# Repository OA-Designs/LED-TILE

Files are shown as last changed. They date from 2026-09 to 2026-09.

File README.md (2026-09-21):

# Modular LED Lighting Tiles

Modular decorative LED tiles in multiple shapes (hex, square, triangle...) sharing one PCB design. Tiles connect edge-to-edge to share power and sync lighting effects across a network. This project is a work in progress and incomplete.

## Overview

Each tile is an independent, battery-powered LED node built around an ESP32-C3, with USB-C charging and a shared power/data bus that lets tiles connect edge to edge. Tiles can pull power from and push power to their neighbors, so a single plugged-in tile can charge several unpowered neighbors at once. The same PCB design drops into enclosures of different shapes (hexagon, square, triangle, pentagon, circular), so the electronics are built once and reused across every form factor.

**Key design points:**
- **Priority power management:** a hardware power mux automatically prefers wired USB power over battery, with no firmware involvement, so LEDs always run off wired power when it's available and switch to battery seamlessly when it's not.
- **LiFePO4 battery charging:** a dedicated charger IC handles battery charging independently of the tile's own power draw, so charging doesn't compete with LED brightness for current budget.
- **Tile-to-tile mesh network:** tiles discover their neighbors automatically over a UART mesh, elect a master per connected group ("island"), and stream synchronized lighting effects across the whole group enabling smooth cross-tile animations like spirals and waves that flow across tile boundaries.
- **Multi-island coordination:** each island's master connects over WiFi to a central coordinator, so multiple physically separate groups of tiles can be synced together.
- **Shape-agnostic PCB:** the same board and firmware work across every enclosure shape; only the physical tile body changes.

## Status

Schematic and PCB layout are complete (4-layer board, DRC clean). Not yet fabricated or bench-tested — feedback and review are very welcome before I send this off for manufacturing.

## Repo Structure
- **Electronics:**          KiCad project files for the shared PCB (schematic, layout, plots)
- **Enclosures:**           Mechanical designs for each tile shape (hexagon, square, triangle, etc.)
- **Docs:**                 Design notes, shared dimensions reference, process history

## View the PCB

The full schematic and PCB layout can be explored interactively (pan, zoom, toggle layers, click any trace to see its net) via KiCanvas:
PLACEHOLDERS
- [Schematic](https://kicanvas.org/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)
- [PCB Layout](https://kicanvas.org/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)

## Design Process

This design went through several rounds of community feedback before reaching its current state — including a full rework of the power/charging circuit, switching to an external-antenna module for layout flexibility, and a move from 2 to 4 layers to resolve routing density. If you're curious about the reasoning behind specific decisions, feel free to open an issue or start a discussion.

## License

Licensed under [GNU GPL v3.0](LICENSE). Modifications and derivatives must remain open source under the same license.

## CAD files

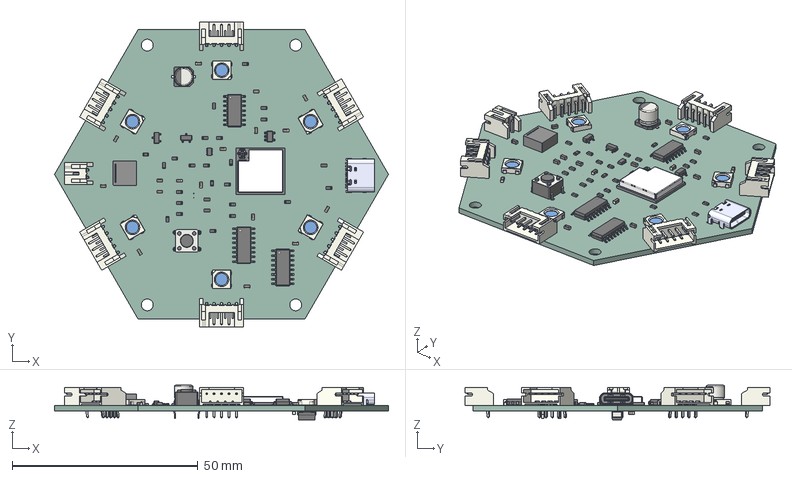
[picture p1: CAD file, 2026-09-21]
electronics/lighting-tile-pcb/Lighting Tile Circuit V3.step
90.0 x 82.1 x 9.30 mm
C_0603_1608Metric x 18
R_0603_1608Metric x 26
LED_WS2812B_PLCC4_50x50mm_P32mm x 6
JST_S2B_PH_K
SW_PUSH_6mm
JST_S5B_PH_K x 6
XAL6030-102MEB
SOT-23-5
SOT-23 x 2
CP_Elec_5x54
TYPE-C-31-M-12
SOIC-14_3.9x8.7mm_P1.27mm
C0402_20210301.STEP^C0402_20210301.STEP_Submodel-C0402_part_ DesignRootModel_PCB_ESP32-C3-MINI-1U_V2(2)_PCB_ESP32-C3-MINI-1U_V2
R0201_20210301.STEP^R0201_20210301.STEP_Submodel-R0201_part_ DesignRootModel_PCB_ESP32-C3-MINI-1U_V2(2)_PCB_ESP32-C3-MINI-1U_V2 x 3
L0201_20210301.STEP^L0201_20210301.STEP_Submodel-L0201_part_ DesignRootModel_PCB_ESP32-C3-MINI-1U_V2(2)_PCB_ESP32-C3-MINI-1U_V2 x 2
C0201_20210301.STEP^C0201_20210301.STEP_Submodel-C0201_part_ DesignRootModel_PCB_ESP32-C3-MINI-1U_V2(2)_PCB_ESP32-C3-MINI-1U_V2 x 11
ESP32-C3_20210301.STEP^ESP32-C3_20210301.STEP_Submodel-QFN32_0P5_5_ part_DesignRootModel_PCB_ESP32-C3-MINI-1U_V2(2)_PCB_ESP32-C3-MINI-1U_V2
DFN1006.STEP^DFN1006.STEP_Submodel-SOD882_part_DesignRootModel_PCB_ ESP32-C3-MINI-1U_V2(2)_PCB_ESP32-C3-MINI-1U_V2
XTAL3225_20210301.STEP^XTAL3225_20210301.STEP_Submodel-XTAL3225_part_ DesignRootModel_PCB_ESP32-C3-MINI-1U_V2(2)_PCB_ESP32-C3-MINI-1U_V2
ipx3.STEP^ipx3.STEP_Submodel-IPEX_4P_part_DesignRootModel_PCB_ ESP32-C3-MINI-1U_V2(2)_PCB_ESP32-C3-MINI-1U_V2
uid__4^DesignRootModel_PCB_ESP32-C3-MINI-1U_V2(2)_PCB_ESP32-C3-MINI-1U_ V2
uid__4-15^DesignRootModel_PCB_ESP32-C3-MINI-1U_V2(2)_PCB_ ESP32-C3-MINI-1U_V2
uid__4-16^DesignRootModel_PCB_ESP32-C3-MINI-1U_V2(2)_PCB_ ESP32-C3-MINI-1U_V2
uid__4-17^DesignRootModel_PCB_ESP32-C3-MINI-1U_V2(2)_PCB_ ESP32-C3-MINI-1U_V2
uid__4-18^DesignRootModel_PCB_ESP32-C3-MINI-1U_V2(2)_PCB_ ESP32-C3-MINI-1U_V2
uid__4-19^DesignRootModel_PCB_ESP32-C3-MINI-1U_V2(2)_PCB_ ESP32-C3-MINI-1U_V2
uid__4-20^DesignRootModel_PCB_ESP32-C3-MINI-1U_V2(2)_PCB_ ESP32-C3-MINI-1U_V2
uid__4-21^DesignRootModel_PCB_ESP32-C3-MINI-1U_V2(2)_PCB_ ESP32-C3-MINI-1U_V2
uid__4-22^DesignRootModel_PCB_ESP32-C3-MINI-1U_V2(2)_PCB_ ESP32-C3-MINI-1U_V2
uid__4-23^DesignRootModel_PCB_ESP32-C3-MINI-1U_V2(2)_PCB_ ESP32-C3-MINI-1U_V2
uid__4-24^DesignRootModel_PCB_ESP32-C3-MINI-1U_V2(2)_PCB_ ESP32-C3-MINI-1U_V2
uid__4-25^DesignRootModel_PCB_ESP32-C3-MINI-1U_V2(2)_PCB_ ESP32-C3-MINI-1U_V2
uid__4-26^DesignRootModel_PCB_ESP32-C3-MINI-1U_V2(2)_PCB_ ESP32-C3-MINI-1U_V2
uid__4-37^DesignRootModel_PCB_ESP32-C3-MINI-1U_V2(2)_PCB_ ESP32-C3-MINI-1U_V2
uid__4-38^DesignRootModel_PCB_ESP32-C3-MINI-1U_V2(2)_PCB_ ESP32-C3-MINI-1U_V2
uid__4-48^DesignRootModel_PCB_ESP32-C3-MINI-1U_V2(2)_PCB_ ESP32-C3-MINI-1U_V2
uid__4-49^DesignRootModel_PCB_ESP32-C3-MINI-1U_V2(2)_PCB_ ESP32-C3-MINI-1U_V2
uid__4-58^DesignRootModel_PCB_ESP32-C3-MINI-1U_V2(2)_PCB_ ESP32-C3-MINI-1U_V2
uid__4-59^DesignRootModel_PCB_ESP32-C3-MINI-1U_V2(2)_PCB_ ESP32-C3-MINI-1U_V2
uid__4-65^DesignRootModel_PCB_ESP32-C3-MINI-1U_V2(2)_PCB_ ESP32-C3-MINI-1U_V2
uid__4-66^DesignRootModel_PCB_ESP32-C3-MINI-1U_V2(2)_PCB_ ESP32-C3-MINI-1U_V2
uid__4-67^DesignRootModel_PCB_ESP32-C3-MINI-1U_V2(2)_PCB_ ESP32-C3-MINI-1U_V2
uid__4-69^DesignRootModel_PCB_ESP32-C3-MINI-1U_V2(2)_PCB_ ESP32-C3-MINI-1U_V2
uid__4-70^DesignRootModel_PCB_ESP32-C3-MINI-1U_V2(2)_PCB_ ESP32-C3-MINI-1U_V2
uid__4-76^DesignRootModel_PCB_ESP32-C3-MINI-1U_V2(2)_PCB_ ESP32-C3-MINI-1U_V2
uid__4-77^DesignRootModel_PCB_ESP32-C3-MINI-1U_V2(2)_PCB_ ESP32-C3-MINI-1U_V2
uid__4-84^DesignRootModel_PCB_ESP32-C3-MINI-1U_V2(2)_PCB_ ESP32-C3-MINI-1U_V2
uid__4-85^DesignRootModel_PCB_ESP32-C3-MINI-1U_V2(2)_PCB_ ESP32-C3-MINI-1U_V2
uid__4-87^DesignRootModel_PCB_ESP32-C3-MINI-1U_V2(2)_PCB_ ESP32-C3-MINI-1U_V2
uid__4-88^DesignRootModel_PCB_ESP32-C3-MINI-1U_V2(2)_PCB_ ESP32-C3-MINI-1U_V2
uid__4-89^DesignRootModel_PCB_ESP32-C3-MINI-1U_V2(2)_PCB_ ESP32-C3-MINI-1U_V2
uid__4-91^DesignRootModel_PCB_ESP32-C3-MINI-1U_V2(2)_PCB_ ESP32-C3-MINI-1U_V2
uid__4-92^DesignRootModel_PCB_ESP32-C3-MINI-1U_V2(2)_PCB_ ESP32-C3-MINI-1U_V2
uid__4-100^DesignRootModel_PCB_ESP32-C3-MINI-1U_V2(2)_PCB_ ESP32-C3-MINI-1U_V2
uid__4-101^DesignRootModel_PCB_ESP32-C3-MINI-1U_V2(2)_PCB_ ESP32-C3-MINI-1U_V2
uid__4-110^DesignRootModel_PCB_ESP32-C3-MINI-1U_V2(2)_PCB_ ESP32-C3-MINI-1U_V2
uid__4-111^DesignRootModel_PCB_ESP32-C3-MINI-1U_V2(2)_PCB_ ESP32-C3-MINI-1U_V2
uid__4-112^DesignRootModel_PCB_ESP32-C3-MINI-1U_V2(2)_PCB_ ESP32-C3-MINI-1U_V2
uid__4-113^DesignRootModel_PCB_ESP32-C3-MINI-1U_V2(2)_PCB_ ESP32-C3-MINI-1U_V2
uid__4-117^DesignRootModel_PCB_ESP32-C3-MINI-1U_V2(2)_PCB_ ESP32-C3-MINI-1U_V2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

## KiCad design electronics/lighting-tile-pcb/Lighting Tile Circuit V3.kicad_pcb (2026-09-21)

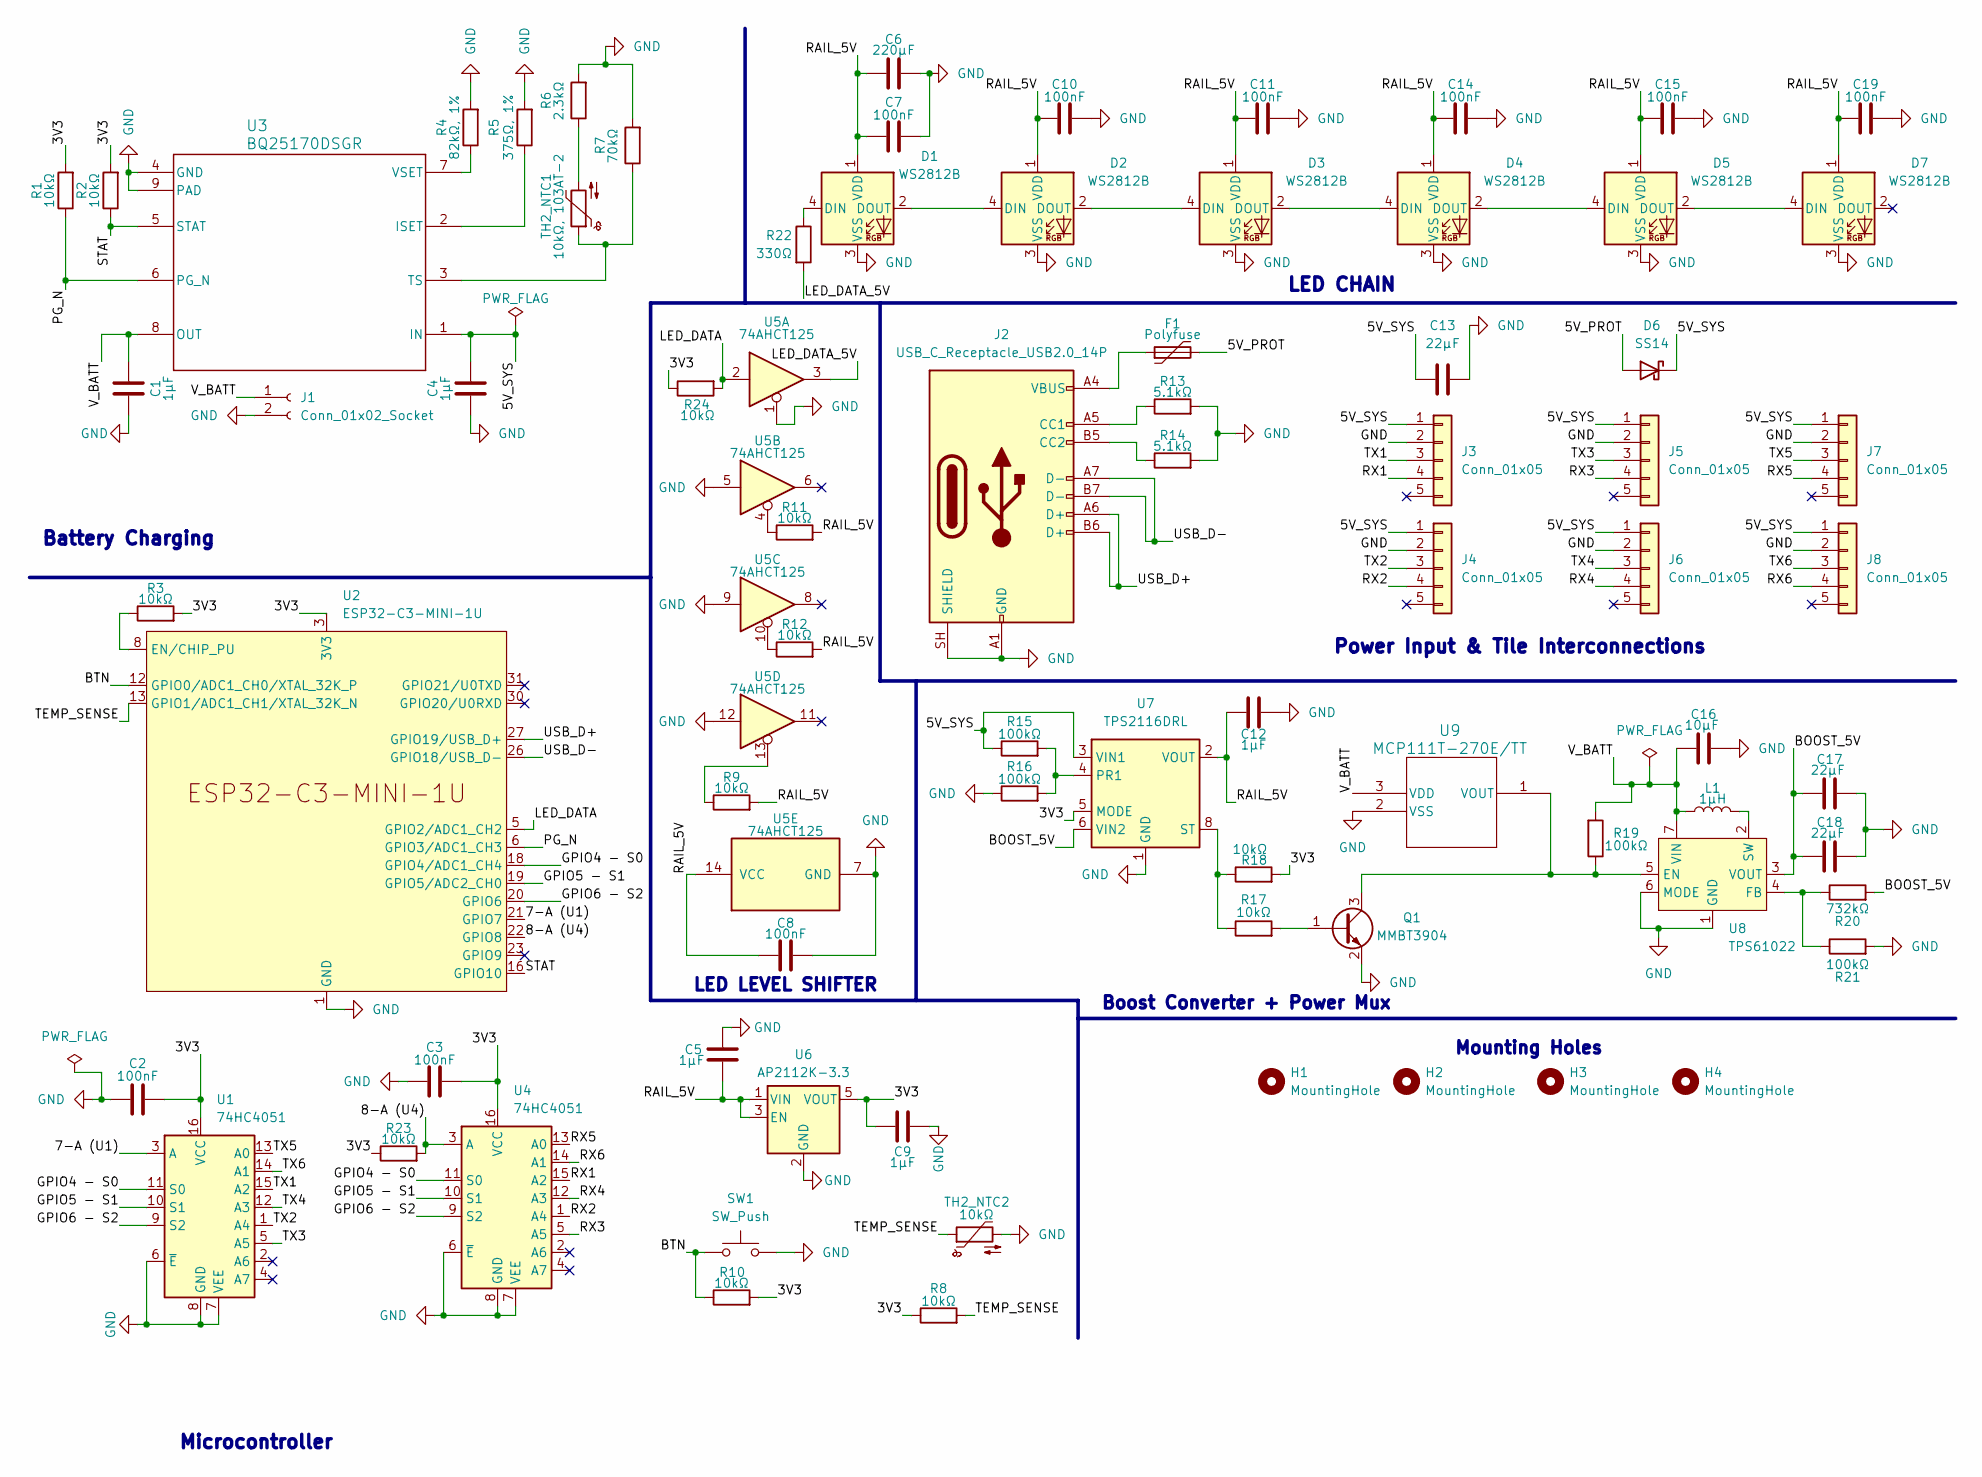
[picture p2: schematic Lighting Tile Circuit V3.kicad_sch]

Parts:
C1, C4, C5, C9: 1µF; C_0603_1608Metric_Pad1.08x0.95mm_HandSolder
C2, C3, C7, C8, C10, C11, C14, C15, C19: 100nF; C_0603_1608Metric_Pad1.08x0.95mm_HandSolder
C6: 220µF; CP_Elec_5x5.4
C12: 1μF; C_0603_1608Metric_Pad1.08x0.95mm_HandSolder
C13: 22µF; C_0603_1608Metric_Pad1.08x0.95mm_HandSolder
C16: 10μF; C_0603_1608Metric_Pad1.08x0.95mm_HandSolder
C17, C18: 22μF; C_0603_1608Metric_Pad1.08x0.95mm_HandSolder
D1, D2, D3, D4, D5, D7: WS2812B; LED_WS2812B_PLCC4_5.0x5.0mm_P3.2mm
D6: SS14; D_SMA
F1: Polyfuse; Fuse_1210_3225Metric_Pad1.42x2.65mm_HandSolder
H1, H2, H3, H4: MountingHole; MountingHole_3.2mm_M3
J1: Conn_01x02_Socket; JST_PH_S2B-PH-K_1x02_P2.00mm_Horizontal
J2: USB_C_Receptacle_USB2.0_14P; USB_C_Receptacle_HRO_TYPE-C-31-M-12
J3, J4, J5, J6, J7, J8: Conn_01x05; JST_PH_S5B-PH-K_1x05_P2.00mm_Horizontal
L1: 1μH; IND_XAL6030-102MEC
Q1: MMBT3904; SOT-23_Handsoldering
R1, R2, R3, R8, R9, R10, R11, R12, R17, R18, R23, R24: 10kΩ; R_0603_1608Metric_Pad0.98x0.95mm_HandSolder
R4: 82kΩ, 1%; R_0603_1608Metric_Pad0.98x0.95mm_HandSolder
R5: 375Ω, 1%; R_0603_1608Metric_Pad0.98x0.95mm_HandSolder
R6: 2.3kΩ; R_0603_1608Metric_Pad0.98x0.95mm_HandSolder
R7: 70kΩ; R_0603_1608Metric_Pad0.98x0.95mm_HandSolder
R13, R14: 5.1kΩ; R_0603_1608Metric_Pad0.98x0.95mm_HandSolder
R15, R16, R19, R21: 100kΩ; R_0603_1608Metric_Pad0.98x0.95mm_HandSolder
R20: 732kΩ; R_0603_1608Metric_Pad0.98x0.95mm_HandSolder
R22: 330Ω; R_0603_1608Metric_Pad0.98x0.95mm_HandSolder
SW1: SW_Push; SW_PUSH_6mm
TH2_NTC1: 10kΩ, 103AT-2; R_0603_1608Metric_Pad0.98x0.95mm_HandSolder
TH2_NTC2: 10kΩ; R_0603_1608Metric_Pad0.98x0.95mm_HandSolder
U1, U4: 74HC4051; SOIC-16_3.9x9.9mm_P1.27mm
U2: ESP32-C3-MINI-1U
U3: BQ25170DSGR; DSG0008A
U5: 74AHCT125; SOIC-14_3.9x8.7mm_P1.27mm
U6: AP2112K-3.3; SOT-23-5
U7: TPS2116DRL; SOT-583-8
U8: TPS61022; Texas_RWU0007A_VQFN-7_2x2mm_P0.5mm
U9: MCP111T-270E/TT; SOT-23_Handsoldering

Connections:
/3V3: C2.2, C3.2, C9.1, R1.2, R2.2, R3.2, R8.1, R10.2, R18.2, R23.1, R24.1, U1.16 (VCC), U2.3 (3V3), U4.16 (VCC), U6.5 (VOUT), U7.5 (MODE)
/5V_PROT: D6.2 (A), F1.2
/5V_SYS: C4.2, C13.1, D6.1 (K), J3.1, J4.1, J5.1, J6.1, J7.1, J8.1, R15.1, U3.1 (IN), U7.3 (VIN1)
/7-A (U1): U1.3 (A), U2.21 (GPIO7)
/8-A (U4): R23.2, U2.22 (GPIO8), U4.3 (A)
/BOOST_5V: C17.1, C18.1, R20.2, U7.6 (VIN2), U8.3 (VOUT)
/BTN: R10.1, SW1.1, U2.12 (GPIO0/ADC1_CH0/XTAL_32K_P)
/GPIO4 - S0: U1.11 (S0), U2.18 (GPIO4/ADC1_CH4), U4.11 (S0)
/GPIO5 - S1: U1.10 (S1), U2.19 (GPIO5/ADC2_CH0), U4.10 (S1)
/GPIO6 - S2: U1.9 (S2), U2.20 (GPIO6), U4.9 (S2)
/LED_DATA: R24.2, U2.5 (GPIO2/ADC1_CH2), U5.2
/LED_DATA_5V: R22.2, U5.3
/PG_N: R1.1, U2.6 (GPIO3/ADC1_CH3), U3.6 (PG_N)
/RAIL_5V: C5.1, C6.1, C7.1, C8.1, C10.1, C11.1, C12.1, C14.1, C15.1, C19.1, D1.1 (VDD), D2.1 (VDD), D3.1 (VDD), D4.1 (VDD), D5.1 (VDD), D7.1 (VDD), R9.2, R11.2, R12.2, U5.14 (VCC), U6.1 (VIN), U6.3 (EN), U7.2 (VOUT), U7.7 (VOUT)
/RX1: J3.4, U4.15 (A2)
/RX2: J4.4, U4.1 (A4)
/RX3: J5.4, U4.5 (A5)
/RX4: J6.4, U4.12 (A3)
/RX5: J7.4, U4.13 (A0)
/RX6: J8.4, U4.14 (A1)
/STAT: R2.1, U2.16 (GPIO10), U3.5 (STAT)
/TEMP_SENSE: R8.2, TH2_NTC2.1, U2.13 (GPIO1/ADC1_CH1/XTAL_32K_N)
/TX1: J3.3, U1.15 (A2)
/TX2: J4.3, U1.1 (A4)
/TX3: J5.3, U1.5 (A5)
/TX4: J6.3, U1.12 (A3)
/TX5: J7.3, U1.13 (A0)
/TX6: J8.3, U1.14 (A1)
/USB_D+: J2.A6 (D+), J2.B6 (D+), U2.27 (GPIO19/USB_D+)
/USB_D-: J2.A7 (D-), J2.B7 (D-), U2.26 (GPIO18/USB_D-)
/V_BATT: C1.2, C16.1, J1.1, L1.1, R19.2, U3.8 (OUT), U8.7 (VIN), U9.3 (VDD)
GND: C1.1, C2.1, C3.1, C4.1, C5.2, C6.2, C7.2, C8.2, C9.2, C10.2, C11.2, C12.2, C13.2, C14.2, C15.2, C16.2, C17.2, C18.2, C19.2, D1.3 (VSS), D2.3 (VSS), D3.3 (VSS), D4.3 (VSS), D5.3 (VSS), D7.3 (VSS), J1.2, J2.A1 (GND), J2.A12 (GND), J2.B1 (GND), J2.B12 (GND), J2.SH (SHIELD), J3.2, J4.2, J5.2, J6.2, J7.2, J8.2, Q1.2 (E), R4.2, R5.2, R6.2, R7.2, R13.2, R14.2, R16.1, R21.2, SW1.2, TH2_NTC2.2, U1.6 (~E), U1.7 (VEE), U1.8 (GND), U2.1 (GND), U2.2 (GND), U2.11 (GND), U2.14 (GND), U2.36 (GND), U2.37 (GND), U2.38 (GND), U2.39 (GND), U2.40 (GND), U2.41 (GND), U2.42 (GND), U2.43 (GND), U2.44 (GND), U2.45 (GND), U2.46 (GND), U2.47 (GND), U2.48 (GND), U2.49 (GND), U2.50 (GND), U2.51 (GND), U2.52 (GND), U2.53 (GND), U3.4 (GND), U3.9 (PAD), U3.10, U3.11, U4.6 (~E), U4.7 (VEE), U4.8 (GND), U5.1, U5.5, U5.7 (GND), U5.9, U5.12, U6.2 (GND), U7.1 (GND), U8.1 (GND), U8.6 (MODE), U9.2 (VSS)
unnamed: D1.4 (DIN), R22.1
unnamed: D1.2 (DOUT), D2.4 (DIN)
unnamed: D2.2 (DOUT), D3.4 (DIN)
unnamed: D3.2 (DOUT), D4.4 (DIN)
unnamed: D4.2 (DOUT), D5.4 (DIN)
unnamed: D5.2 (DOUT), D7.4 (DIN)
unnamed: F1.1, J2.A4 (VBUS), J2.A9 (VBUS), J2.B4 (VBUS), J2.B9 (VBUS)
unnamed: J2.A5 (CC1), R13.1
unnamed: J2.B5 (CC2), R14.1
unnamed: Q1.1 (B), R17.2
unnamed: Q1.3 (C), R19.1, U8.5 (EN), U9.1 (VOUT)
unnamed: R6.1, TH2_NTC1.2
unnamed: R9.1, U5.13
unnamed: R11.1, U5.4
unnamed: R12.1, U5.10
unnamed: R3.1, U2.8 (EN/CHIP_PU)
unnamed: R5.1, U3.2 (ISET)
unnamed: R7.1, TH2_NTC1.1, U3.3 (TS)
unnamed: R4.1, U3.7 (VSET)
unnamed: R15.2, R16.2, U7.4 (PR1)
unnamed: R17.1, R18.1, U7.8 (ST)
unnamed: R20.1, R21.1, U8.4 (FB)
unnamed: L1.2, U8.2 (SW)

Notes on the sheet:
Power Input & Tile Interconnections
LED CHAIN
LED LEVEL SHIFTER
Battery Charging
Mounting Holes
Microcontroller
Boost Converter + Power Mux

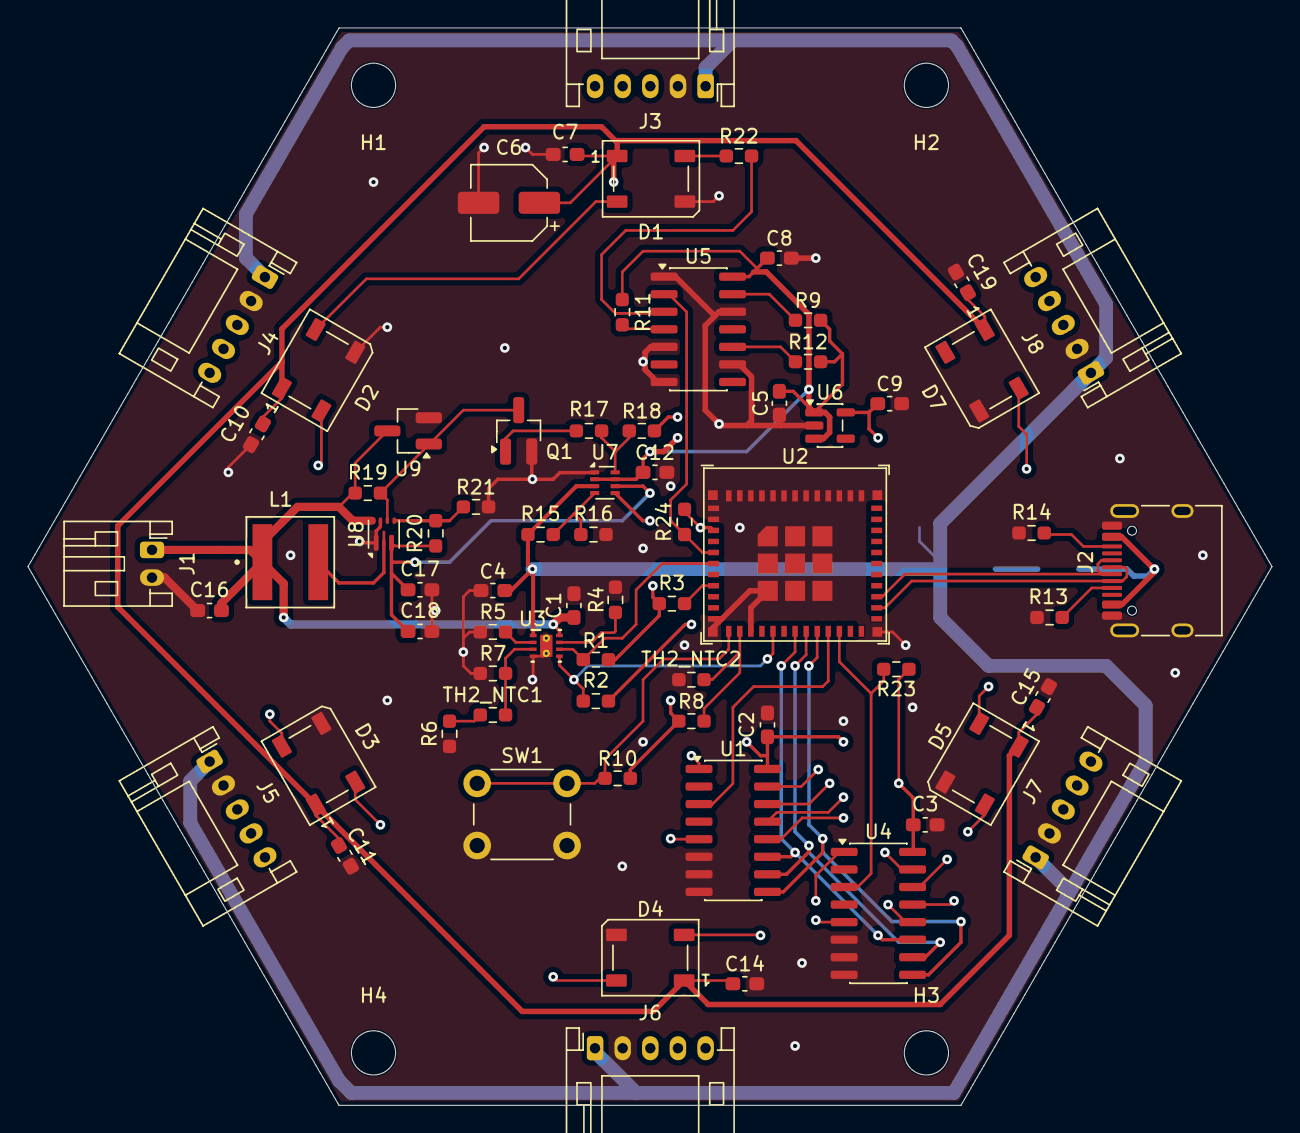
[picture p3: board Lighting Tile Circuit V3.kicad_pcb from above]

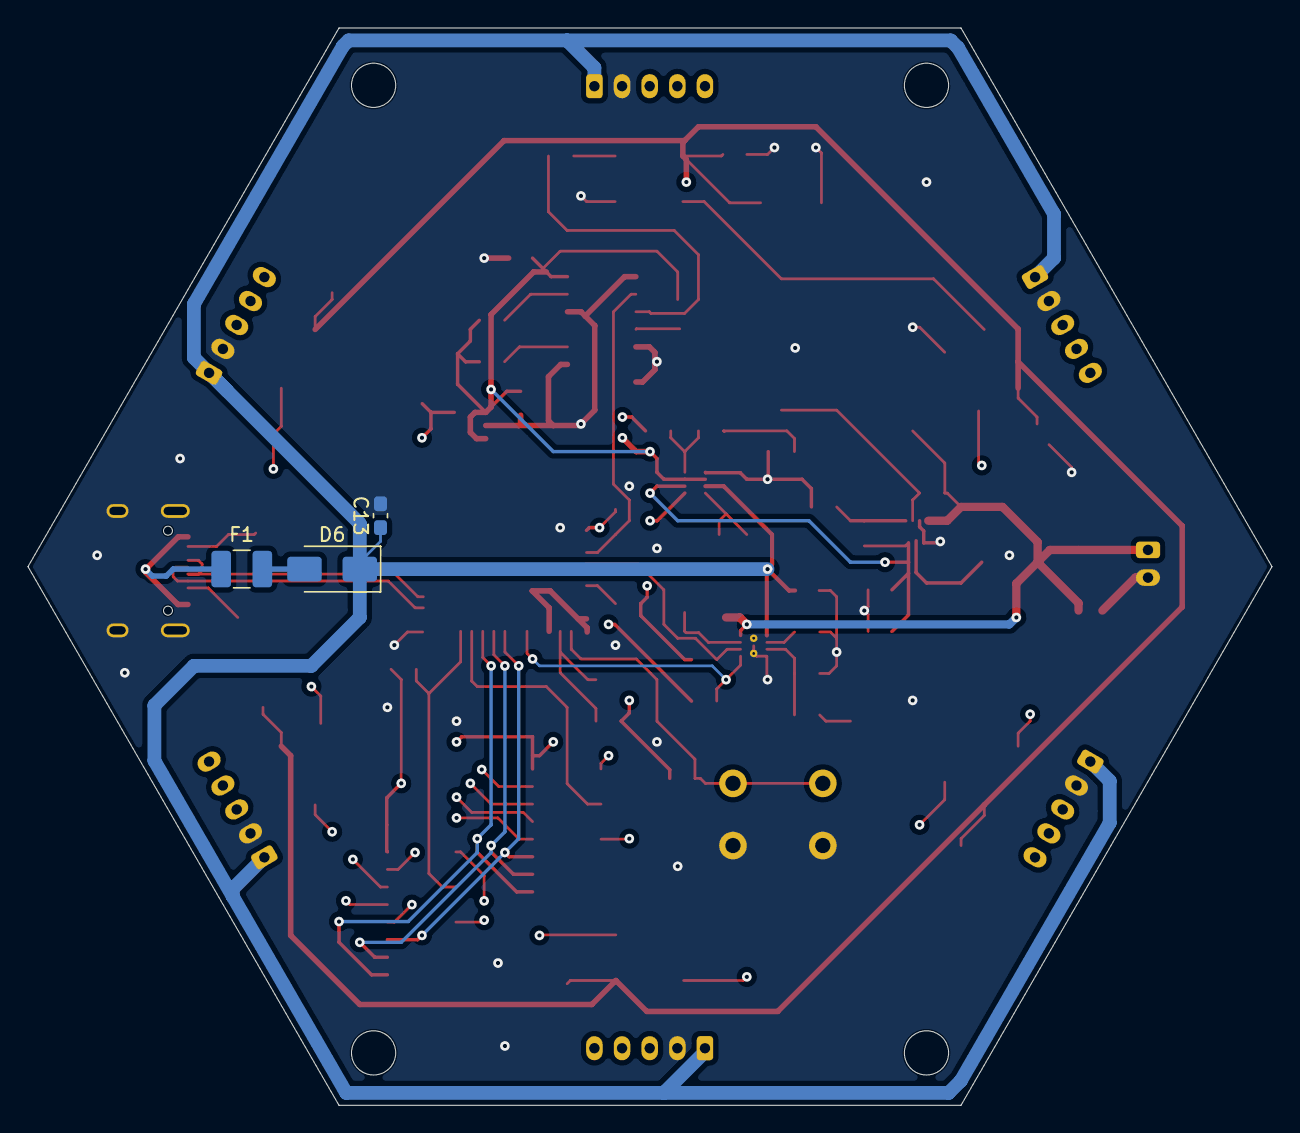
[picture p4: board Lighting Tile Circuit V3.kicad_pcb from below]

Board: 4 copper layers, 90.0 x 77.9 mm, 77 parts (3 on the bottom side), 55 nets.

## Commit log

2026-09-18 Add V2 schematic and PCB files
    [Lighting Tile Circuit V2.kicad_pcb, Lighting Tile Circuit V2.kicad_sch]
2026-09-18 Fixed V2 files
    [Lighting Tile Circuit V2.kicad_pcb, Lighting Tile Circuit V2.kicad_sch]
2026-09-18 Create .gitkeep
    placeholder empty file to keep folders while enclosures are being designed.
2026-09-19 Added V3 Files
    [Lighting Tile Circuit V3.kicad_pcb, Lighting Tile Circuit V3.kicad_sch]
